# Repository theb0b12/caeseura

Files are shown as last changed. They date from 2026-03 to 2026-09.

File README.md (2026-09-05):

# Caeseura

**cae·sue·ra**
/siːˈzʊrə/

**noun**

1. in modern prosody : a usually rhetorical break in the flow of sound in the middle of a line of verse
2. break, interruption
   > "a *caesura* between the movie and its sequel"
3. a pause marking a rhythmic point of division in a melody

[credit](https://www.merriam-webster.com/dictionary/caesura)

***etymology***

Altered spelling of *caesura*, intentionally adding the **e** as wordplay, referencing the spelling of the city of **Céüse** in France, a very cool sport climbing destination and host to some of the hardest routes in the world. The sword **Caesura** from *The Kingkiller Chronicle*, great book btw. And the concept of splitting or dividing (get it, split keebs).

---

## Photos

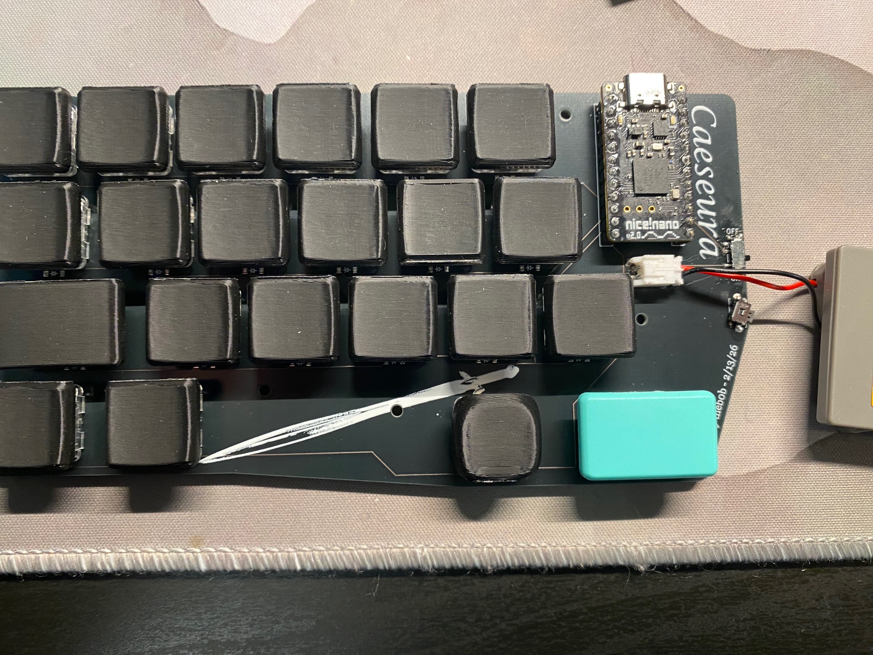
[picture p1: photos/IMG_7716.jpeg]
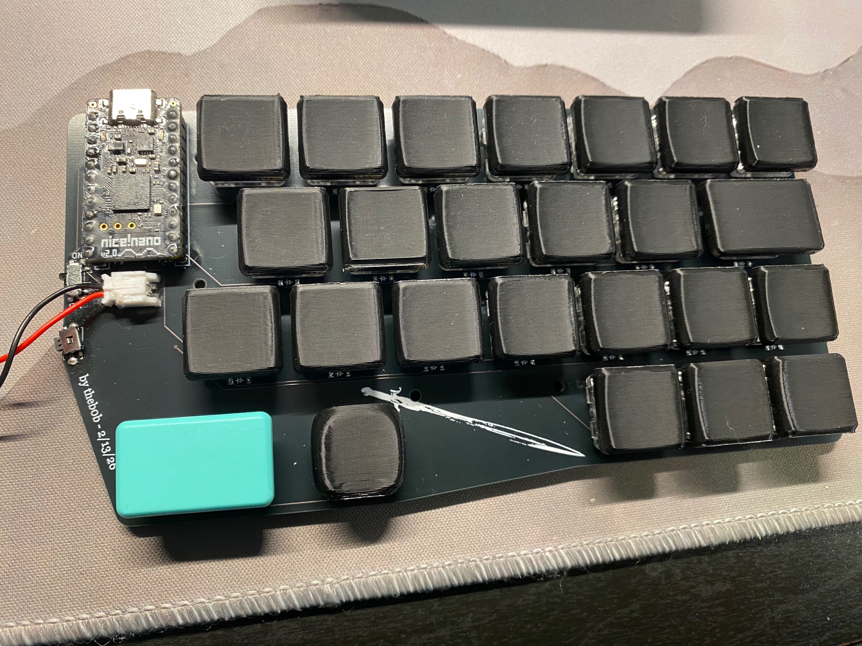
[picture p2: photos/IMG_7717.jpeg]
|  |  |
| :---: | :---: |
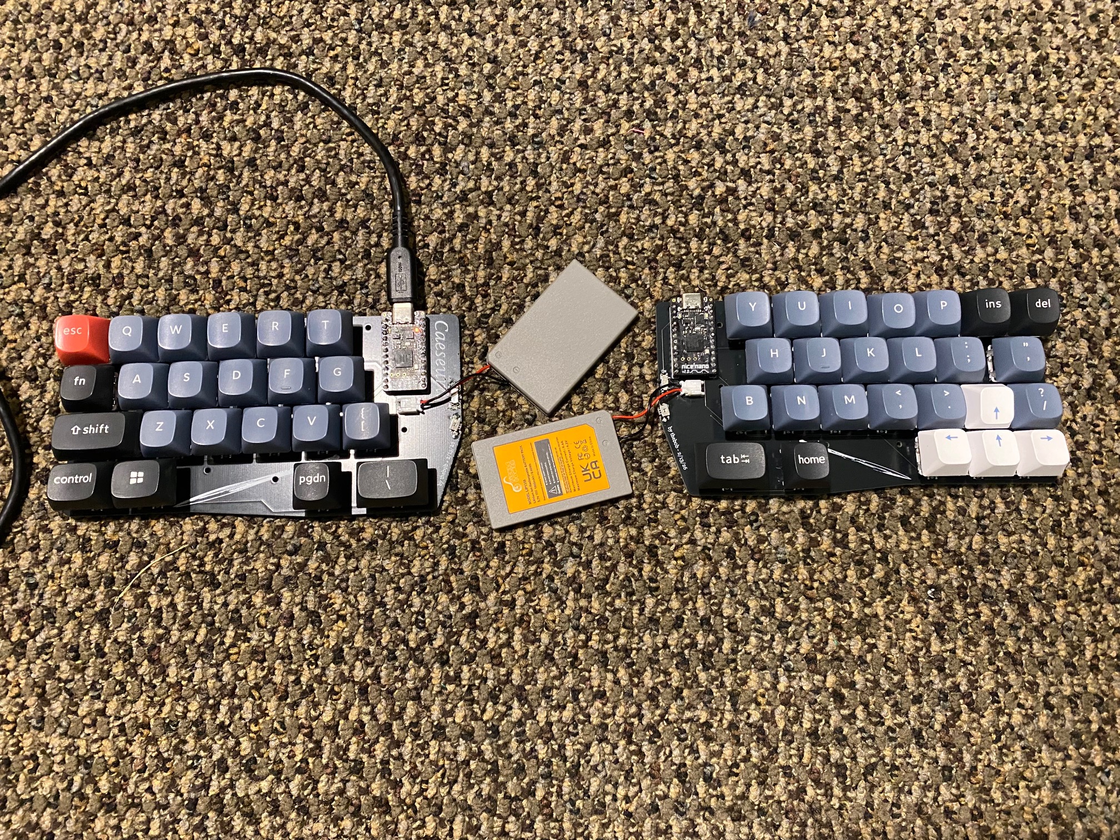
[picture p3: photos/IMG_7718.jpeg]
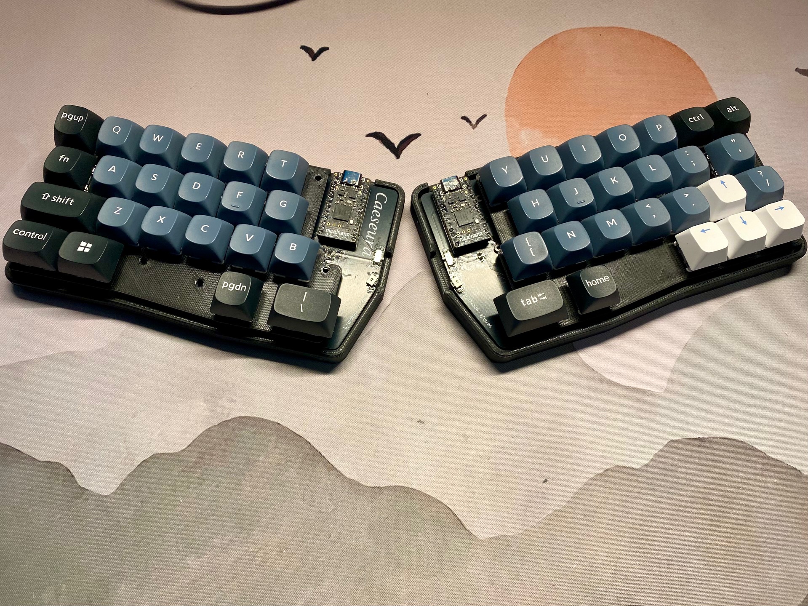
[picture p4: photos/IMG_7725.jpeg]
|  |  |

---

## Builds

<p float="left">
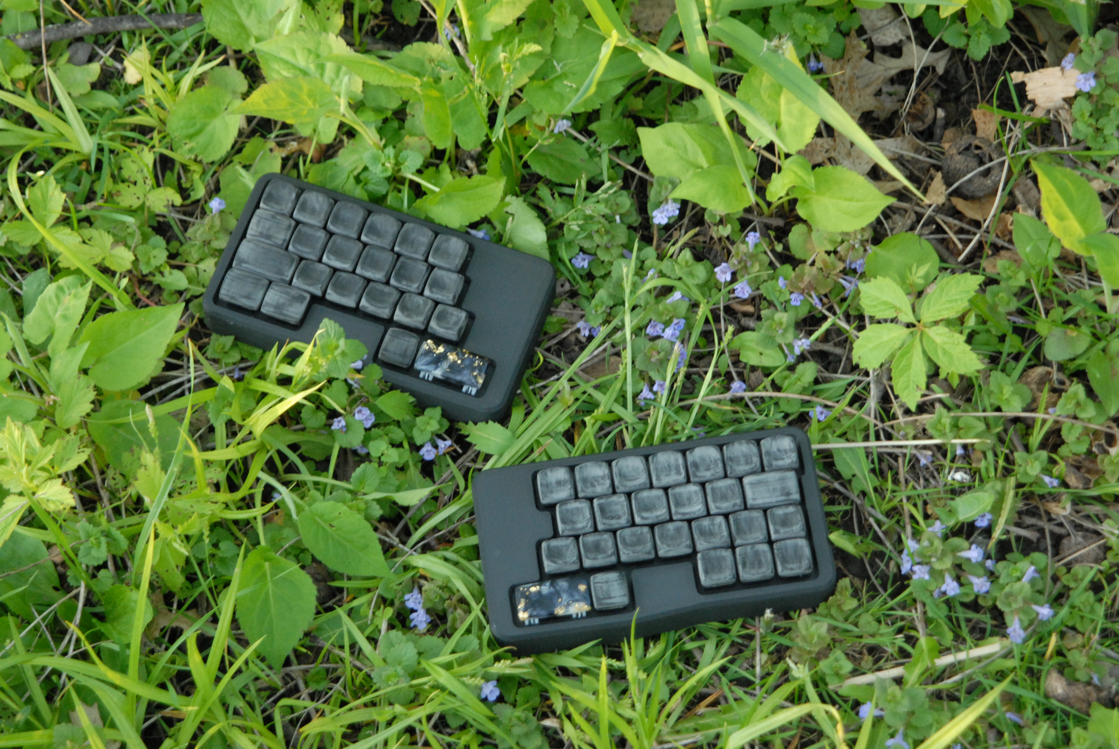
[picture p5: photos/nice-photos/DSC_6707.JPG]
  
  <div align="center">
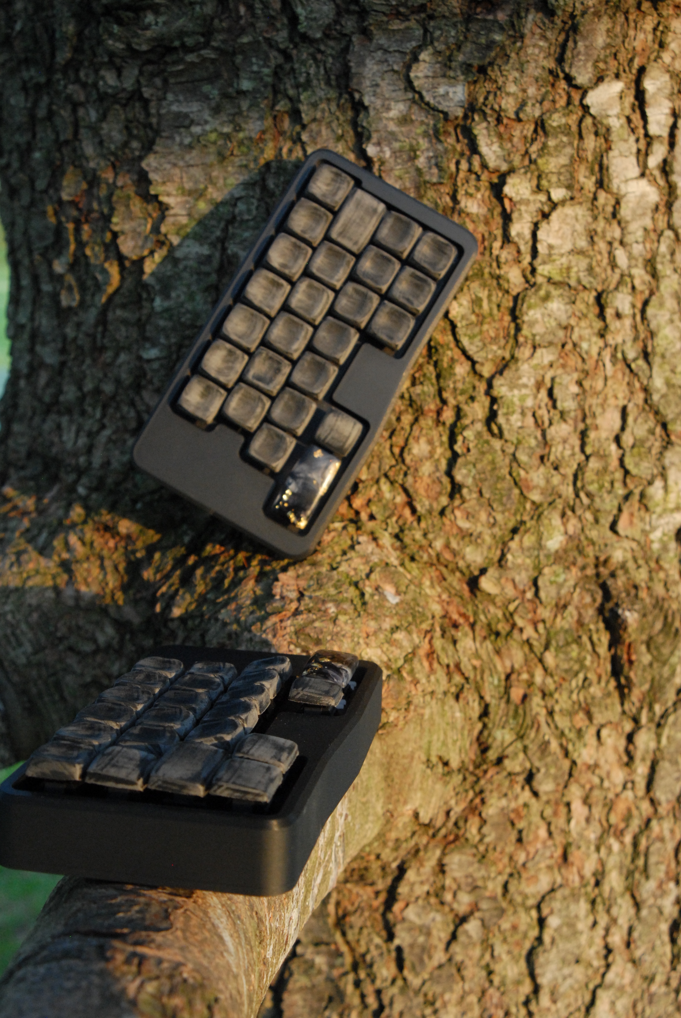
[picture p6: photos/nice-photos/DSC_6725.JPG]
    
  </div>
</p>

Lu's Build, with a custom case and nice Asymplex/3D-printed Subliminal Contraction keycaps

---

<p float="left">
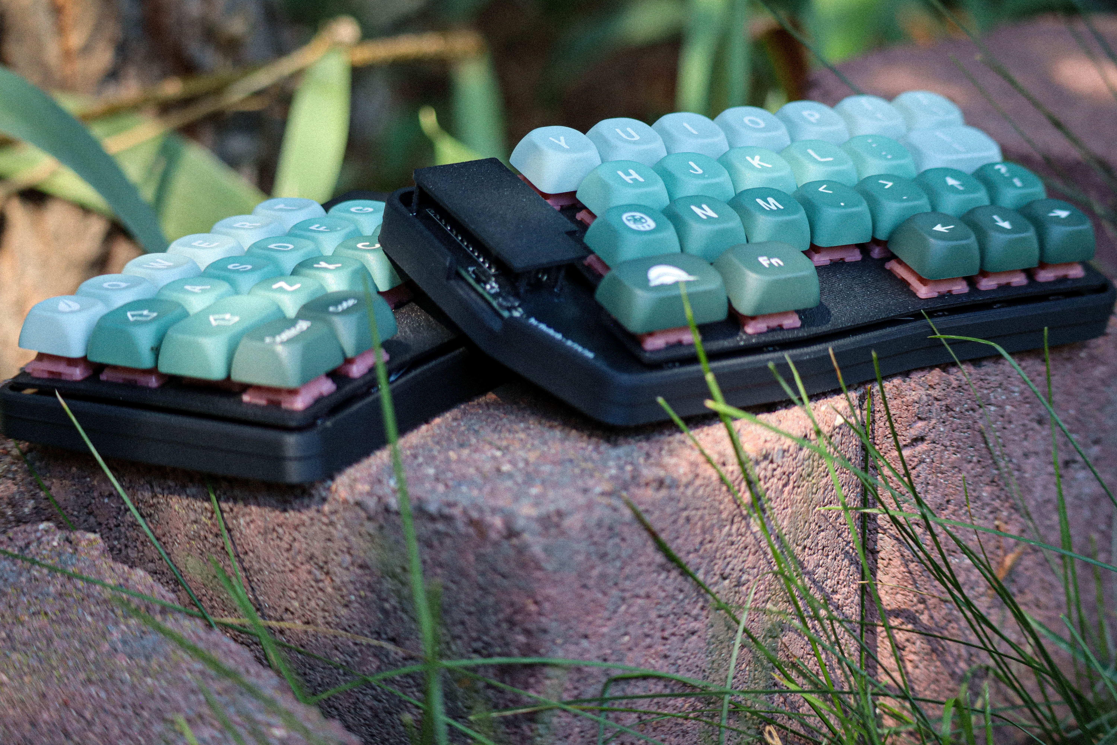
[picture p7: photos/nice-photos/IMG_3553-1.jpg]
    
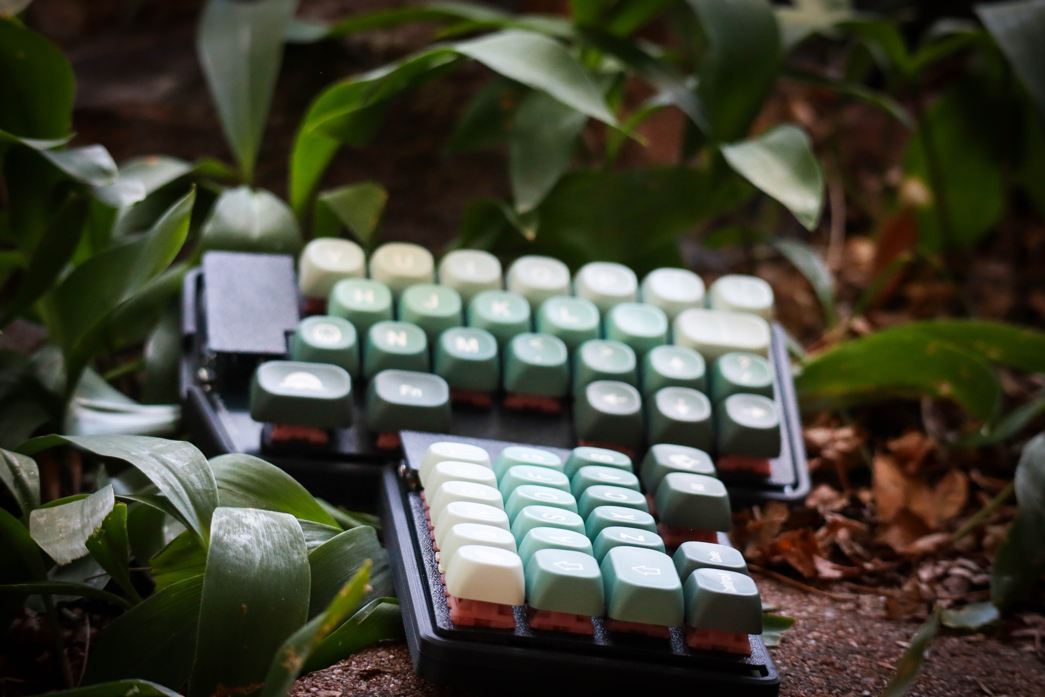
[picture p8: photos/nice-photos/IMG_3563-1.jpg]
    
</p>

My Build, with a custom display cover and nice MOA keycaps

## Features

- **47 keys**
- **Row Staggered**
- **Split design**
- **MX & Choc compatible** - hotswap sockets, choc v1 and v2 (if you snip the extra pin)
- **Wireless** - powered by the [nice!nano v2](https://nicekeyboards.com/nice-nano/) and [ZMK firmware](https://zmk.dev/)
- **Open source** - PCB gerbers + kicad files, case files, ZMK config, and Ergogen YAML

---

## Bill of Materials (BOM)

These are the things from my build. In hindsight I would've changed some things, use it with a couple more than a few grains of salt. Total cost will vary depending on switch choice, shipping, and discounts.

| Item | Qty | Unit Price | Total | Link |
| --- | --- | --- | --- | --- |
| nice!nano v2 | 2 | $25.00 | $50.00  | [Typeractive](https://typeractive.xyz/products/nice-nano) |
| Batteries | 1 set | $15.49 | $15.49  | [Amazon](https://www.amazon.com/dp/B09726K2LC) |
| PCB (left + right) | 1 set | $27.00 | $27.00  | JLCPCB |
| Switches (Choc) | ~47 | - | - | personal choice |
| Choc hotswap sockets (x10) | 5 packs | $1.50 | $7.50 | [Typeractive](https://typeractive.xyz/products/hotswap-sockets?variant=45742200324327) |
| MX hotswap sockets | 5 packs | $1.50 | $7.50 | [Typeractive](https://typeractive.xyz/products/hotswap-sockets?variant=45742200291559) |
| Reset switch (Panasonic EVQ-PUA02K)  | 3 | $0.67 | $2.01 | [Digikey](https://www.digikey.com/en/products/detail/panasonic-electronic-components/EVQ-PUA02K/286334) |
| Power switch (SMD) | 2 packs | $1.50 | $3.00 | [Typeractive](https://typeractive.xyz/products/power-switch) |
| JST PH 2-pin battery connector | 2 | $0.10 | $0.20 | [Digikey](https://www.digikey.com/en/products/detail/jst-sales-america-inc/S2B-PH-K-S/926626) |
| Keycaps | ~47 | - | - | personal choice |
| SOD-123 diodes (1N4148W) | 50 | $0.0495 | $2.48 | [Digikey](https://www.digikey.com/en/products/detail/diotec-semiconductor/1N4148W/18833653) |
| Mill-Max 310 board sockets | 6 | $1.43 | $8.58 | [Digikey](https://www.digikey.com/en/products/detail/mill-max-manufacturing-corp/310-47-112-41-001000/7364039) |
| Mill-Max 3320 pins | 65 | $0.0876 | $5.69 | [Digikey](https://www.digikey.com/en/products/detail/mill-max-manufacturing-corp/3320-0-00-15-00-00-03-0/4147392) |
| Adhesive rubber feet | 1 pack  | $6.99 | $6.99 | [Amazon](https://www.amazon.com/dp/B0DXH5D1FQ) |
| M2x6mm FHCS screws | 1 pack  | $8.69 | $8.69 | [Amazon](https://www.amazon.com/dp/B01MYRN6A1) |
| M2 heat-set inserts | 1 pack  | $6.99 | $6.99 | [Amazon](https://www.amazon.com/dp/B0FJXLNMLM) |

---

## Build Guide

WIP

---

## Credits

### Designer

Built and designed by **[@theb0b12](https://github.com/theb0b12)**.

### Special Thanks

A massive shout-out to **[@stardustArc](https://github.com/stardustArc)** - she essentially walked me through the entire design and build process step by step. This keyboard would not exist without her help.

Big thanks to **[@zakwaykway](https://github.com/zakwaykway)** for his knowledge about switches and switch footprints, invaluable when figuring out the dual MX/Choc hotswap setup.

Shout-out to the **[Ergogen Discord](https://discord.com/invite/DbCfZfZ)** and the **[ZMK Discord](https://discord.com/invite/sycytVQ)** communities, the collective knowledge in both servers made this project possible.

Thanks to **[@genteure](https://github.com/genteure)** for his help with the board shield and his excellent tool **[ZMK Shield Wizard](https://shield-wizard.genteure.workers.dev/)**, which makes setting up custom ZMK shields dramatically easier.

### Tools & Stuff

- **[Ergogen](https://ergogen.xyz/)**
- **[ceoloide footprint library](https://github.com/ceoloide/ergogen-footprints)**
- **[ZMK Firmware](https://zmk.dev/)**
- **[nice!nano](https://nicekeyboards.com/nice-nano/)**
- **[ZMK Shield Wizard](https://shield-wizard.genteure.workers.dev/)**
- **[Keymap Layout Tools](https://nickcoutsos.github.io/keymap-layout-tools/)**
- **[Keymap Editor](https://nickcoutsos.github.io/keymap-editor/)**

---

## License

This project is open source with the AGPLv3 license. PCB design files, case files, and ZMK config are free to use, modify, and build from. If you make changes and share them, a link back here would be appreciated.

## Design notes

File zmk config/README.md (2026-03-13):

# ZMK Configuration for Caeseura

*Generated by Shield Wizard for ZMK*

Keyboard Layout

Download compiled firmware from the Actions tab. <https://zmk.dev/docs/user-setup#installing-the-firmware>

Edit your keymap <https://zmk.dev/docs/keymaps>.
User keymap is located at [`config/caeseura.keymap`](config/caeseura.keymap).

-----

<details>
<summary>
Shield Wizard Debug Information
</summary>

In case of broken configuration, here is the Shield Wizard internal data used to generate this configuration:

Commit: 8a52249f61161469b6d90ed8c80c4aa52b9f3858

```json
{"name":"Caeseura","shield":"caeseura","dongle":false,"modules":[],"layout":[{"id":"01KJEWSTA2WSGJPKTC9RK0804X","part":0,"row":0,"col":0,"w":1,"h":1,"x":-10,"y":0,"r":0,"rx":0,"ry":0},{"id":"01KJEWSTA2ZQ8XTTBYFGZP5PSZ","part":0,"row":0,"col":1,"w":1,"h":1,"x":-8.944,"y":0,"r":0,"rx":0,"ry":0},{"id":"01KJEWSTA2C88EE1QST33JA1P6","part":0,"row":0,"col":2,"w":1,"h":1,"x":-7.889,"y":0,"r":0,"rx":0,"ry":0},{"id":"01KJEWSTA2G5R2BWYK12CTZR03","part":0,"row":0,"col":3,"w":1,"h":1,"x":-6.833,"y":0,"r":0,"rx":0,"ry":0},{"id":"01KJEWSTA21AFNH5VCJ36AK0GV","part":0,"row":0,"col":4,"w":1,"h":1,"x":-5.778,"y":0,"r":0,"rx":0,"ry":0},{"id":"01KJEWSTA2W56V2A9YR1CV8M3E","part":0,"row":0,"col":5,"w":1,"h":1,"x":-4.722,"y":0,"r":0,"rx":0,"ry":0},{"id":"01KJEWSTA2ES13WSG7RSGPF13B","part":1,"row":0,"col":6,"w":1,"h":1,"x":0.556,"y":0,"r":0,"rx":0,"ry":0},{"id":"01KJEWSTA2R7YCBS51QP8ZYZ7D","part":1,"row":0,"col":7,"w":1,"h":1,"x":1.611,"y":0,"r":0,"rx":0,"ry":0},{"id":"01KJEWSTA2TFBK0J2W7EZJKC5F","part":1,"row":0,"col":8,"w":1,"h":1,"x":2.667,"y":0,"r":0,"rx":0,"ry":0},{"id":"01KJEWSTA2DXHBZF197RBKKWGA","part":1,"row":0,"col":9,"w":1,"h":1,"x":3.722,"y":0,"r":0,"rx":0,"ry":0},{"id":"01KJEWSTA2T3FJJ22BCS2JE90N","part":1,"row":0,"col":10,"w":1,"h":1,"x":4.778,"y":0,"r":0,"rx":0,"ry":0},{"id":"01KJEWSTA2P0ZJ9EZSFYXTD83C","part":1,"row":0,"col":11,"w":1,"h":1,"x":5.833,"y":0,"r":0,"rx":0,"ry":0},{"id":"01KJEWSTA21GZ6KJEF5EMBP04D","part":1,"row":0,"col":12,"w":1,"h":1,"x":6.889,"y":0,"r":0,"rx":0,"ry":0},{"id":"01KJEWSTA21TCHPA67XRTKVNZ1","part":0,"row":1,"col":0,"w":1,"h":1,"x":-9.868,"y":1.118,"r":0,"rx":0,"ry":0},{"id":"01KJEWSTA292T44RCXD0JPR47B","part":0,"row":1,"col":1,"w":1,"h":1,"x":-8.681,"y":1.118,"r":0,"rx":0,"ry":0},{"id":"01KJEWSTA24PVX6M598WA1QNJP","part":0,"row":1,"col":2,"w":1,"h":1,"x":-7.625,"y":1.118,"r":0,"rx":0,"ry":0},{"id":"01KJEWSTA2TQ3HEGQECEQQF0VR","part":0,"row":1,"col":3,"w":1,"h":1,"x":-6.569,"y":1.118,"r":0,"rx":0,"ry":0},{"id":"01KJEWSTA2D1HMF334DAMVJ7CN","part":0,"row":1,"col":4,"w":1,"h":1,"x":-5.514,"y":1.118,"r":0,"rx":0,"ry":0},{"id":"01KJEWSTA27SRSSCDMWXE4JTVZ","part":0,"row":1,"col":5,"w":1,"h":1,"x":-4.458,"y":1.118,"r":0,"rx":0,"ry":0},{"id":"01KJEWSTA2H7VHF5TAGFCWHR83","part":1,"row":1,"col":6,"w":1,"h":1,"x":0.946,"y":1.118,"r":0,"rx":0,"ry":0},{"id":"01KJEWSTA2H20N2C6QSN041Y61","part":1,"row":1,"col":7,"w":1,"h":1,"x":2.002,"y":1.118,"r":0,"rx":0,"ry":0},{"id":"01KJEWSTA2ZA9CGH6RQDM98WP8","part":1,"row":1,"col":8,"w":1,"h":1,"x":3.057,"y":1.118,"r":0,"rx":0,"ry":0},{"id":"01KJEWSTA28KYFTZ1JEKM1T4DR","part":1,"row":1,"col":9,"w":1,"h":1,"x":4.113,"y":1.118,"r":0,"rx":0,"ry":0},{"id":"01KJEWSTA2THR0P5A34MPB1QS1","part":1,"row":1,"col":10,"w":1,"h":1,"x":5.168,"y":1.118,"r":0,"rx":0,"ry":0},{"id":"01KJEWSTA20MWT175GMZAQT9SH","part":1,"row":1,"col":11,"w":1,"h":1,"x":6.488,"y":1.118,"r":0,"rx":0,"ry":0},{"id":"01KJEWSTA299AXM0DHS4MQ8TJK","part":0,"row":2,"col":0,"w":1,"h":1,"x":-9.604,"y":2.235,"r":0,"rx":0,"ry":0},{"id":"01KJEWSTA2M2N71XEZR4HPK0W6","part":0,"row":2,"col":1,"w":1,"h":1,"x":-8.153,"y":2.235,"r":0,"rx":0,"ry":0},{"id":"01KJEWSTA2DJFHSKAZW4RR8BVA","part":0,"row":2,"col":2,"w":1,"h":1,"x":-7.097,"y":2.235,"r":0,"rx":0,"ry":0},{"id":"01KJEWSTA20ZCJ6W2HSM25F4P7","part":0,"row":2,"col":3,"w":1,"h":1,"x":-6.042,"y":2.235,"r":0,"rx":0,"ry":0},{"id":"01KJEWSTA2MBDPN0T132J9TN9R","part":0,"row":2,"col":4,"w":1,"h":1,"x":-4.986,"y":2.235,"r":0,"rx":0,"ry":0},{"id":"01KJEWSTA216C8V17B20HJKZDJ","part":0,"row":2,"col":5,"w":1,"h":1,"x":-3.931,"y":2.235,"r":0,"rx":0,"ry":0},{"id":"01KJEWSTA28NBBCRCYW7ZXF3M2","part":1,"row":2,"col":6,"w":1,"h":1,"x":0.389,"y":2.235,"r":0,"rx":0,"ry":0},{"id":"01KJEWSTA23FXD1VXMPVAH9RP0","part":1,"row":2,"col":7,"w":1,"h":1,"x":1.444,"y":2.235,"r":0,"rx":0,"ry":0},{"id":"01KJEWSTA2F8Y84D5SXWWX4PK8","part":1,"row":2,"col":8,"w":1,"h":1,"x":2.5,"y":2.235,"r":0,"rx":0,"ry":0},{"id":"01KJEWSTA2YW7S3QYV2QCXJQKW","part":1,"row":2,"col":9,"w":1,"h":1,"x":3.556,"y":2.235,"r":0,"rx":0,"ry":0},{"id":"01KJEWSTA2RJGC1BJTTPVNAVV4","part":1,"row":2,"col":10,"w":1,"h":1,"x":4.611,"y":2.235,"r":0,"rx":0,"ry":0},{"id":"01KJEWSTA25J43D66Q70EFGXG6","part":1,"row":2,"col":11,"w":1,"h":1,"x":5.667,"y":2.235,"r":0,"rx":0,"ry":0},{"id":"01KJEWSTA2C54XKHV0RGHAS2NJ","part":1,"row":2,"col":12,"w":1,"h":1,"x":6.722,"y":2.235,"r":0,"rx":0,"ry":0},{"id":"01KJEWSTA2QAYRH0BNK577YBGJ","part":0,"row":3,"col":0,"w":1,"h":1,"x":-9.868,"y":3.353,"r":0,"rx":0,"ry":0},{"id":"01KJEWSTA21G4BVSW8682JX6P5","part":0,"row":3,"col":1,"w":1,"h":1,"x":-8.554,"y":3.353,"r":0,"rx":0,"ry":0},{"id":"01KJEWSTA2S40B1S4S66GGR2KC","part":0,"row":3,"col":4,"w":1,"h":1,"x":-4.961,"y":3.576,"r":0,"rx":0,"ry":0},{"id":"01KJEWSTA20YM5P2QC0KJ4WFHA","part":0,"row":3,"col":5,"w":1,"h":1,"x":-3.35,"y":3.576,"r":0,"rx":0,"ry":0},{"id":"01KJEWSTA2MYZP26JJ3H6RK6KW","part":1,"row":3,"col":6,"w":1,"h":1,"x":0,"y":3.576,"r":0,"rx":0,"ry":0},{"id":"01KJEWSTA2V0EV06EGKYDJBW3G","part":1,"row":3,"col":7,"w":1,"h":1,"x":1.583,"y":3.576,"r":0,"rx":0,"ry":0},{"id":"01KJEWSTA2WJKBQ5BQ5GR7PT27","part":1,"row":3,"col":10,"w":1,"h":1,"x":4.611,"y":3.353,"r":0,"rx":0,"ry":0},{"id":"01KJEWSTA2W9J5XBYBK5B0S5GC","part":1,"row":3,"col":11,"w":1,"h":1,"x":5.667,"y":3.353,"r":0,"rx":0,"ry":0},{"id":"01KJEWSTA2M5JD10PPGRHJZ0V6","part":1,"row":3,"col":12,"w":1,"h":1,"x":6.722,"y":3.353,"r":0,"rx":0,"ry":0}],"parts":[{"name":"left","controller":"nice_nano_v2","wiring":"matrix_diode","pins":{"d4":"output","d3":"output","d2":"output","d1":"output","d0":"output","d6":"input","d7":"input","d8":"input","d5":"output","d9":"input"},"keys":{"01KJEWSTA2W56V2A9YR1CV8M3E":{"input":"d6","output":"d5"},"01KJEWSTA27SRSSCDMWXE4JTVZ":{"input":"d7","output":"d5"},"01KJEWSTA216C8V17B20HJKZDJ":{"input":"d8","output":"d5"},"01KJEWSTA21AFNH5VCJ36AK0GV":{"input":"d6","output":"d4"},"01KJEWSTA2D1HMF334DAMVJ7CN":{"input":"d7","output":"d4"},"01KJEWSTA2MBDPN0T132J9TN9R":{"input":"d8","output":"d4"},"01KJEWSTA2G5R2BWYK12CTZR03":{"input":"d6","output":"d3"},"01KJEWSTA2TQ3HEGQECEQQF0VR":{"input":"d7","output":"d3"},"01KJEWSTA20ZCJ6W2HSM25F4P7":{"input":"d8","output":"d3"},"01KJEWSTA2C88EE1QST33JA1P6":{"input":"d6","output":"d2"},"01KJEWSTA2DJFHSKAZW4RR8BVA":{"input":"d8","output":"d2"},"01KJEWSTA24PVX6M598WA1QNJP":{"input":"d7","output":"d2"},"01KJEWSTA2ZQ8XTTBYFGZP5PSZ":{"input":"d6","output":"d1"},"01KJEWSTA292T44RCXD0JPR47B":{"input":"d7","output":"d1"},"01KJEWSTA2M2N71XEZR4HPK0W6":{"input":"d8","output":"d1"},"01KJEWSTA21G4BVSW8682JX6P5":{"input":"d9","output":"d1"},"01KJEWSTA2WSGJPKTC9RK0804X":{"input":"d6","output":"d0"},"01KJEWSTA21TCHPA67XRTKVNZ1":{"input":"d7","output":"d0"},"01KJEWSTA299AXM0DHS4MQ8TJK":{"input":"d8","output":"d0"},"01KJEWSTA2QAYRH0BNK577YBGJ":{"input":"d9","output":"d0"},"01KJEWSTA20YM5P2QC0KJ4WFHA":{"input":"d9","output":"d5"},"01KJEWSTA2S40B1S4S66GGR2KC":{"input":"d9","output":"d4"}},"encoders":[],"buses":[{"name":"spi0","devices":[],"type":"spi"},{"name":"spi1","devices":[],"type":"spi"},{"name":"spi2","devices":[],"type":"spi"},{"name":"spi3","devices":[],"type":"spi"},{"name":"i2c0","devices":[],"type":"i2c"},{"name":"i2c1","devices":[],"type":"i2c"}]},{"name":"right","controller":"nice_nano_v2","wiring":"matrix_diode","pins":{"d1":"output","d0":"output","d2":"output","d3":"output","d4":"output","d5":"output","d6":"output","d7":"input","d8":"input","d9":"input","d10":"input","d14":"input"},"keys":{"01KJEWSTA2R7YCBS51QP8ZYZ7D":{"input":"d7","output":"d1"},"01KJEWSTA2H20N2C6QSN041Y61":{"input":"d8","output":"d1"},"01KJEWSTA2V0EV06EGKYDJBW3G":{"input":"d14","output":"d1"},"01KJEWSTA23FXD1VXMPVAH9RP0":{"input":"d9","output":"d1"},"01KJEWSTA2MYZP26JJ3H6RK6KW":{"input":"d14","output":"d0"},"01KJEWSTA28NBBCRCYW7ZXF3M2":{"input":"d9","output":"d0"},"01KJEWSTA2H7VHF5TAGFCWHR83":{"input":"d8","output":"d0"},"01KJEWSTA2ES13WSG7RSGPF13B":{"input":"d7","output":"d0"},"01KJEWSTA2F8Y84D5SXWWX4PK8":{"input":"d9","output":"d2"},"01KJEWSTA2ZA9CGH6RQDM98WP8":{"input":"d8","output":"d2"},"01KJEWSTA2TFBK0J2W7EZJKC5F":{"input":"d7","output":"d2"},"01KJEWSTA2YW7S3QYV2QCXJQKW":{"input":"d9","output":"d3"},"01KJEWSTA28KYFTZ1JEKM1T4DR":{"input":"d8","output":"d3"},"01KJEWSTA2DXHBZF197RBKKWGA":{"input":"d7","output":"d3"},"01KJEWSTA2WJKBQ5BQ5GR7PT27":{"input":"d10","output":"d4"},"01KJEWSTA2RJGC1BJTTPVNAVV4":{"input":"d9","output":"d4"},"01KJEWSTA2T3FJJ22BCS2JE90N":{"input":"d7","output":"d4"},"01KJEWSTA2THR0P5A34MPB1QS1":{"input":"d8","output":"d4"},"01KJEWSTA2W9J5XBYBK5B0S5GC":{"input":"d10","output":"d5"},"01KJEWSTA25J43D66Q70EFGXG6":{"input":"d9","output":"d5"},"01KJEWSTA20MWT175GMZAQT9SH":{"input":"d8","output":"d5"},"01KJEWSTA2P0ZJ9EZSFYXTD83C":{"input":"d7","output":"d5"},"01KJEWSTA2M5JD10PPGRHJZ0V6":{"input":"d10","output":"d6"},"01KJEWSTA2C54XKHV0RGHAS2NJ":{"input":"d9","output":"d6"},"01KJEWSTA21GZ6KJEF5EMBP04D":{"input":"d7","output":"d6"}},"encoders":[],"buses":[{"name":"spi0","devices":[],"type":"spi"},{"name":"spi1","devices":[],"type":"spi"},{"name":"spi2","devices":[],"type":"spi"},{"name":"spi3","devices":[],"type":"spi"},{"name":"i2c0","devices":[],"type":"i2c"},{"name":"i2c1","devices":[],"type":"i2c"}]}]}
```

</details>

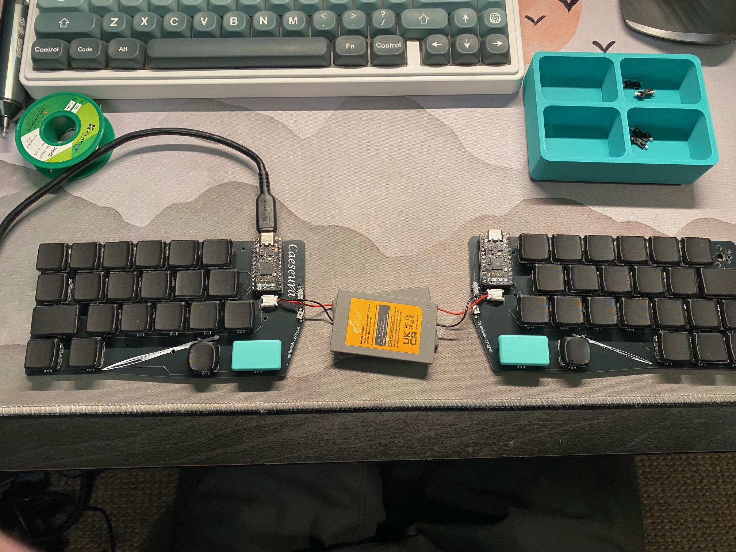
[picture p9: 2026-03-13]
photos/IMG_7715 - Copy.jpeg

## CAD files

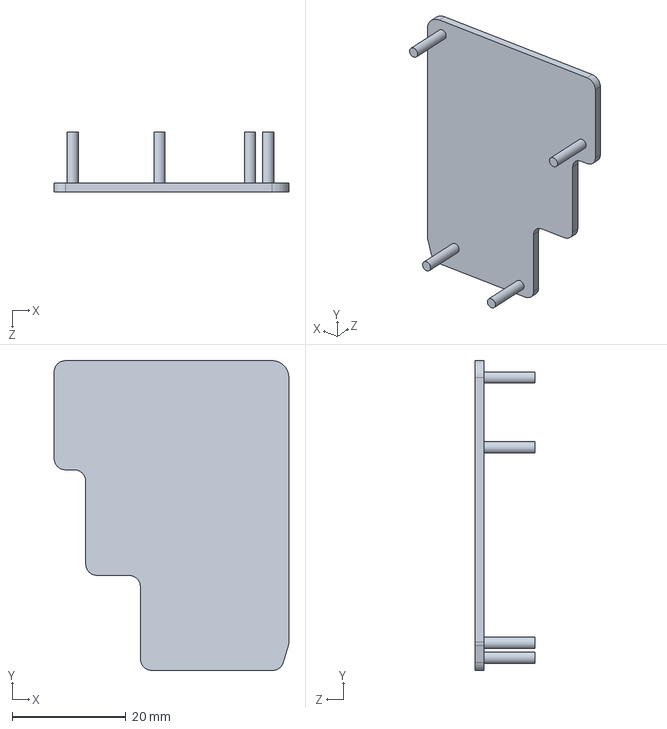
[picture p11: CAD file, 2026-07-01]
cases/left/leftsidecoverv2.SLDPRT
41.4 x 54.6 x 10.6 mm

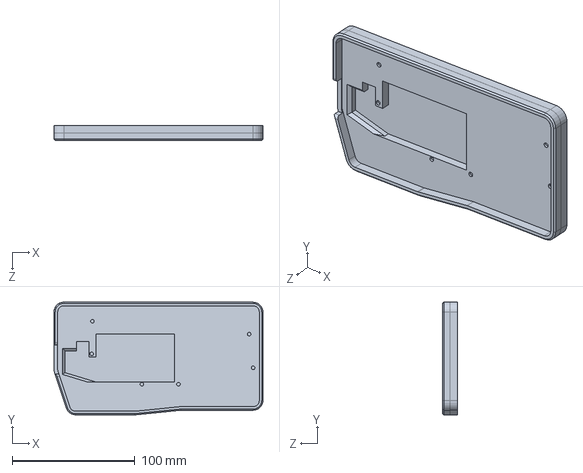
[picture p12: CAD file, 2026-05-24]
cases/right/rightcasebottomv2.SLDPRT
170.3 x 91.9 x 12.0 mm

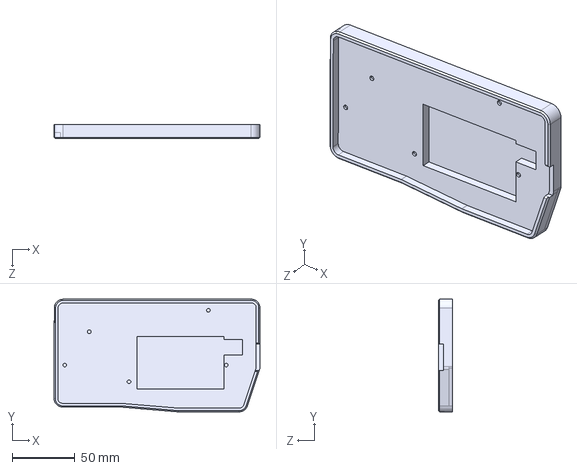
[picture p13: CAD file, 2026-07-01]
cases/left/leftcasebottomv3.STEP
164.2 x 89.9 x 11.2 mm

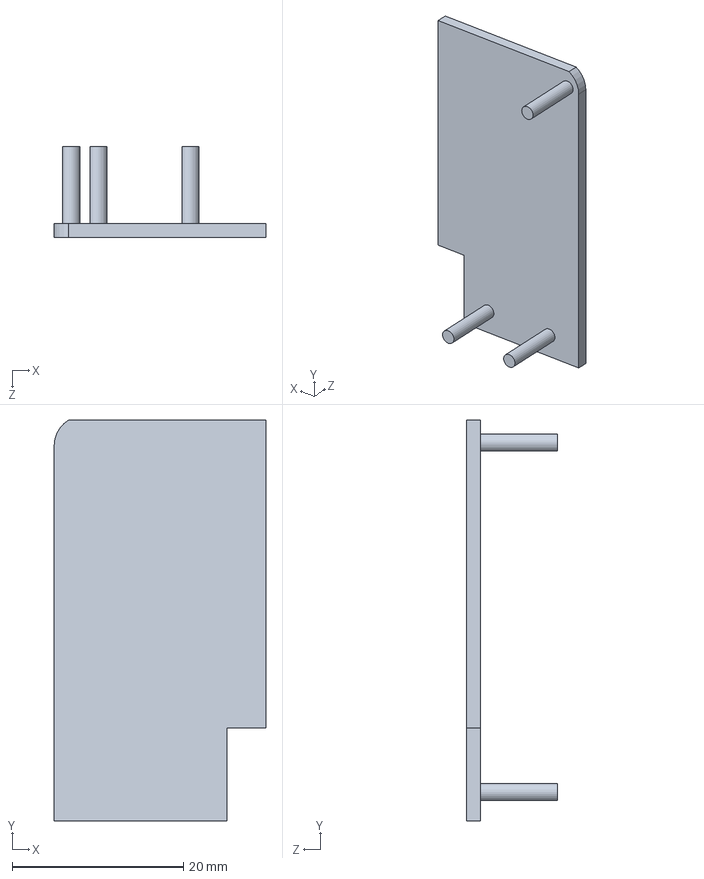
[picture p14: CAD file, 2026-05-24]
cases/right/right side cover.SLDPRT
24.7 x 46.8 x 10.6 mm

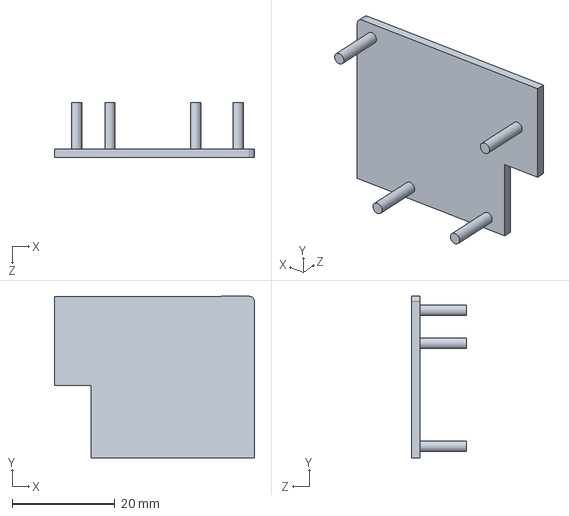
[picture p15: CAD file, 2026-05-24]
cases/left/left side cover.SLDPRT
38.9 x 31.4 x 10.6 mm

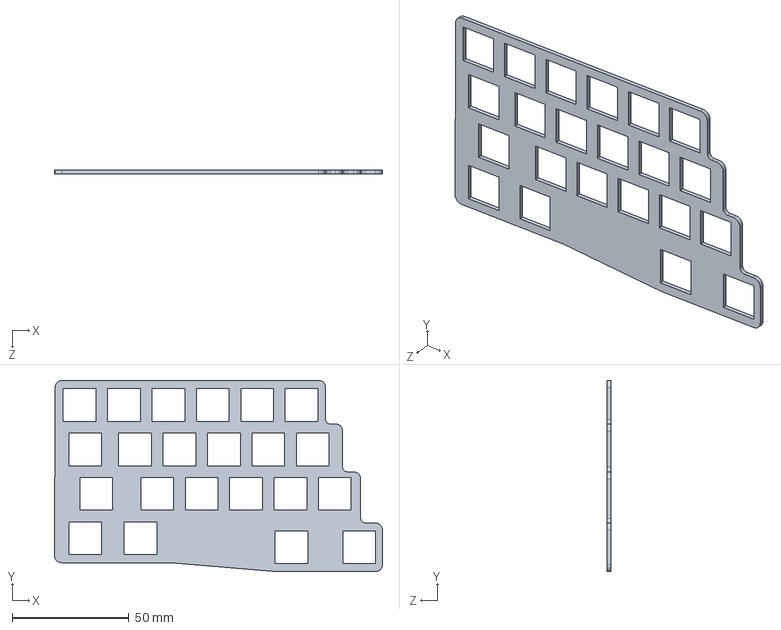
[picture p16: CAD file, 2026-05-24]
cases/left/leftmxswitchplatev2.SLDPRT
140.4 x 81.9 x 1.60 mm

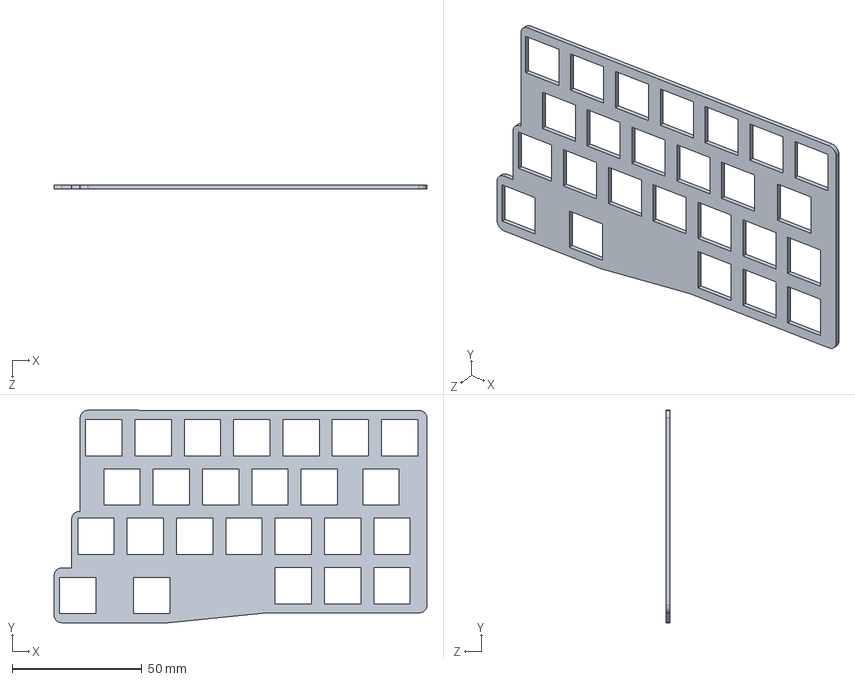
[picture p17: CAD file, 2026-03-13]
cases/right/rightmxswitchplatev1.SLDPRT
143.7 x 81.9 x 1.60 mm

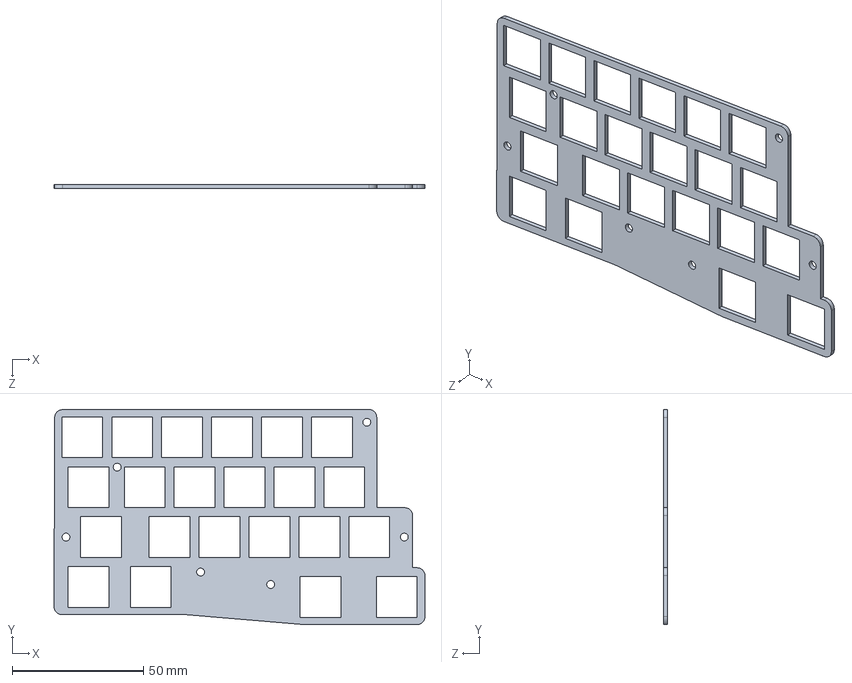
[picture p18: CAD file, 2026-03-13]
cases/left/leftmxswitchplate.SLDPRT
141.2 x 81.9 x 1.60 mm

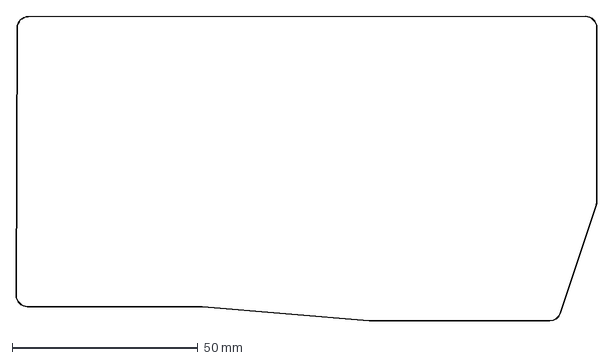
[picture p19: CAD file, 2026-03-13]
cases/left/board.dxf
156.2 x 81.9 mm

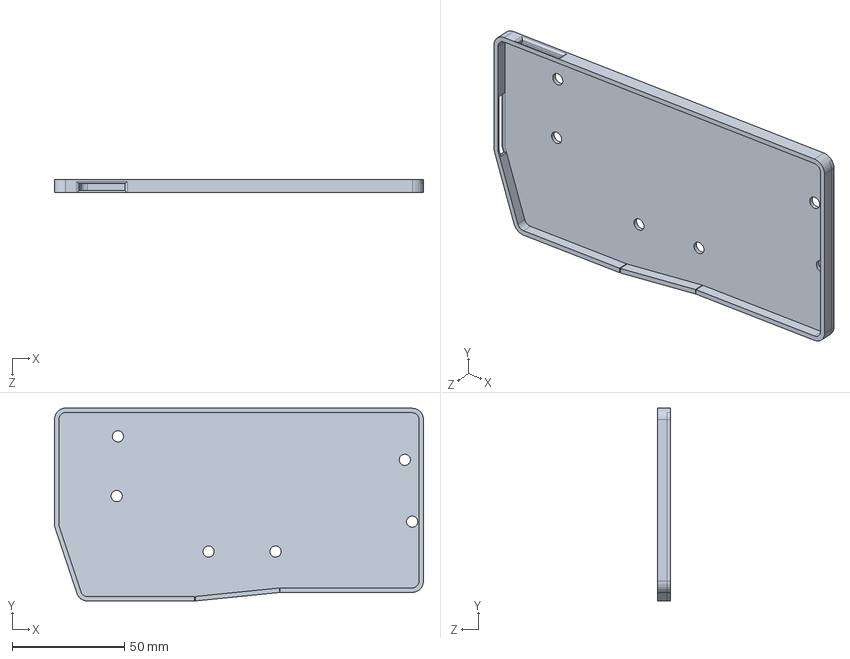
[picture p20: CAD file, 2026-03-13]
cases/right/rightcasebottom.SLDPRT
164.3 x 85.9 x 6.00 mm

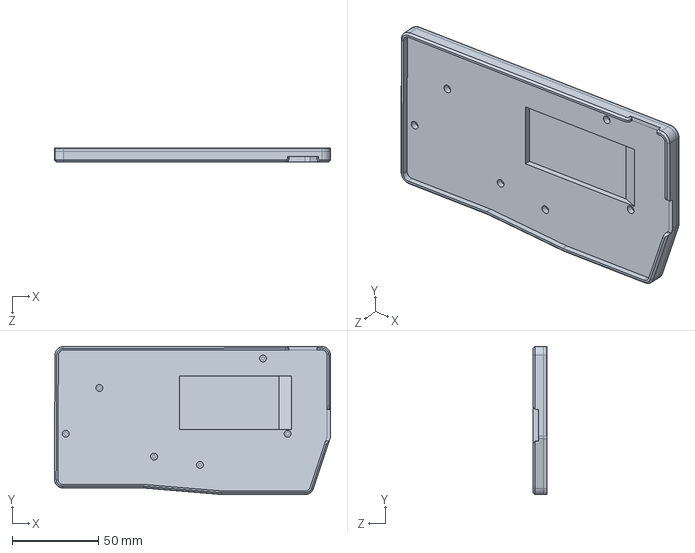
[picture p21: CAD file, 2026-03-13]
cases/left/leftcasebottom.SLDPRT
160.2 x 86.0 x 8.00 mm

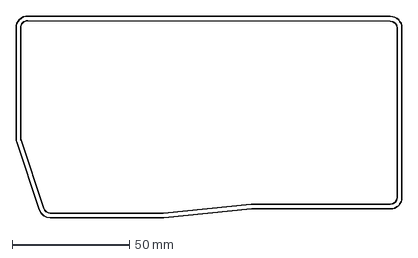
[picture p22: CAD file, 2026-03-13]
cases/right/wall_outline.dxf
164.2 x 85.9 mm

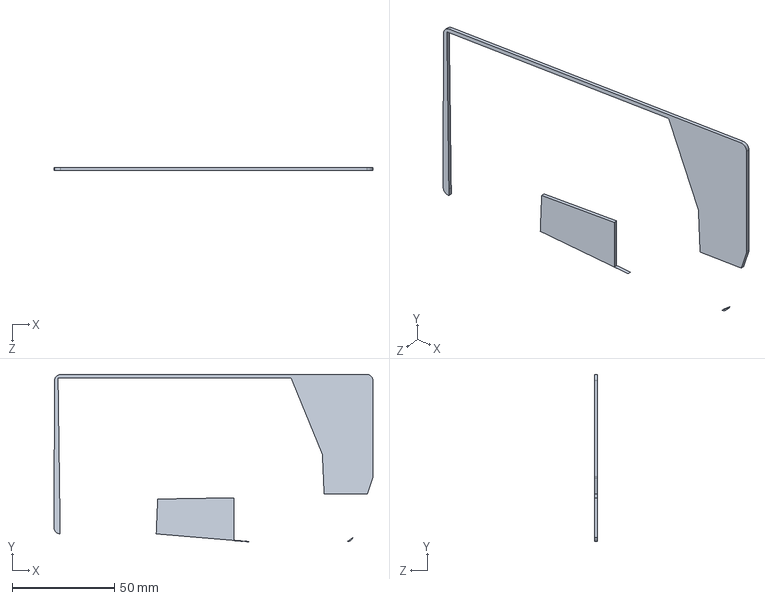
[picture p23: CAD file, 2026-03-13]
cases/left/leftcasetop.SLDPRT
156.2 x 81.9 x 1.60 mm

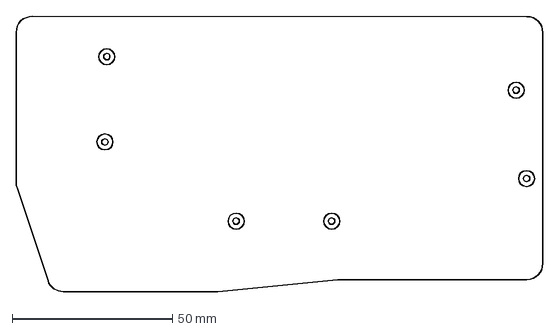
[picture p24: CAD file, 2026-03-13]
cases/right/xlBoard.dxf
164.2 x 85.9 mm

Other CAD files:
cases/left/leftcasebottomv2.SLDPRT
cases/right/switch_plate (2).dxf
cases/left/xlBoard.dxf
cases/left/wall_outline.dxf
cases/left/left side cover.STL
cases/left/leftcasebottom.STL
cases/left/leftcasebottomv2.STL
cases/left/leftcasebottomv3.SLDPRT
cases/left/leftcasebottomv3.STL
cases/left/leftcasetop.STL
cases/left/leftmxswitchplate.STL
cases/left/leftmxswitchplatev2.STL
cases/left/leftsidecoverv2.STL
cases/left/realBoard.dxf
cases/left/wall_outline (1).dxf
cases/right/right side cover.STL
cases/right/rightcasebottom.STL
cases/right/rightcasebottomv2.STL
cases/right/rightmxswitchplatev1.STL
cases/right/wall_outline (2).dxf
cases/right/wall_outline (3).dxf

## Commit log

2026-03-14 Update battery item description in README
2026-04-30 Refine feature descriptions in README.md
    Updated descriptions for compatibility, case, and reset button features.
2026-05-01 fixed the bodge
    [left_pcbv2.kicad_pcb]
2026-05-24 updated pcb and changed photos
    [left side cover.SLDPRT, left side cover.STL, leftcasebottomv3.SLDPRT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]
2026-07-01 added gitignore and updated README
    [leftcasebottomv3.STEP, leftsidecoverv2.SLDPRT, leftsidecoverv2.STL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]
